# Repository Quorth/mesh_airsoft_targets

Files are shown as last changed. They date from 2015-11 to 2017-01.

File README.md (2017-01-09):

# mesh_airsoft_targets

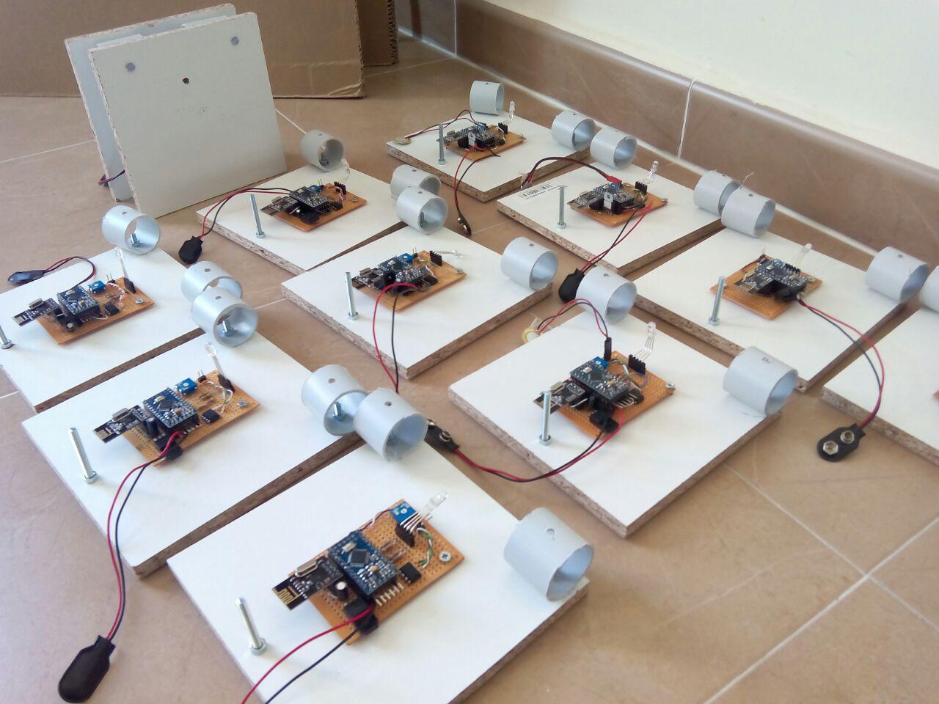
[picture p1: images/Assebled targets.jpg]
Assembled targets


Completed targets (piezo still not glued)

An arduino based airsoft targets with mesh networking capabilities. This is a WIP project originally made for the Murcia Lan Party event. But since it's been stalled for more than a year, we decided to release

We use the nrlf24l01 2.4Ghz modem and the RF24Mesh library to comunicate the targets with the master module

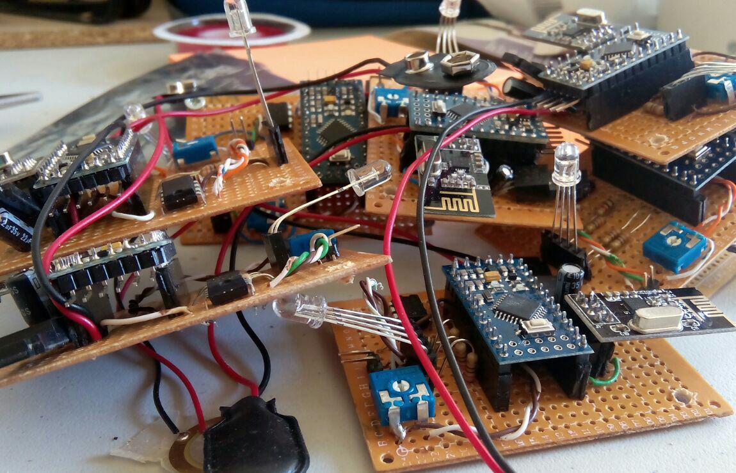
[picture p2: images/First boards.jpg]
First boards


First boards

The targets can control a RGB LED and reports the impacts to the master node, the games are implemented in the master module, so far we only have a sequential game with timing implemented

The impact detection is implemented via a piezoelectric transducer and a opamp for cleaning the pulse and setting sensitivity, you have the eagle schematics in target_node/board

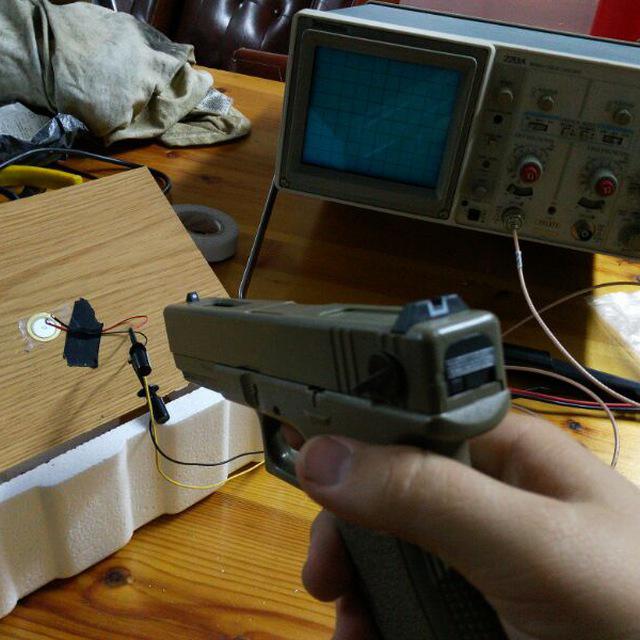
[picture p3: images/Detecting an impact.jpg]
Detecting an impact


Detecting an impact

The master module is an arduino board with a serial connection to the host the same board we use for the targets can be used as a master, but the idea is to eventually port to an OpenWRT target (like a TL703n) for networked operation or a BT link to a phone.

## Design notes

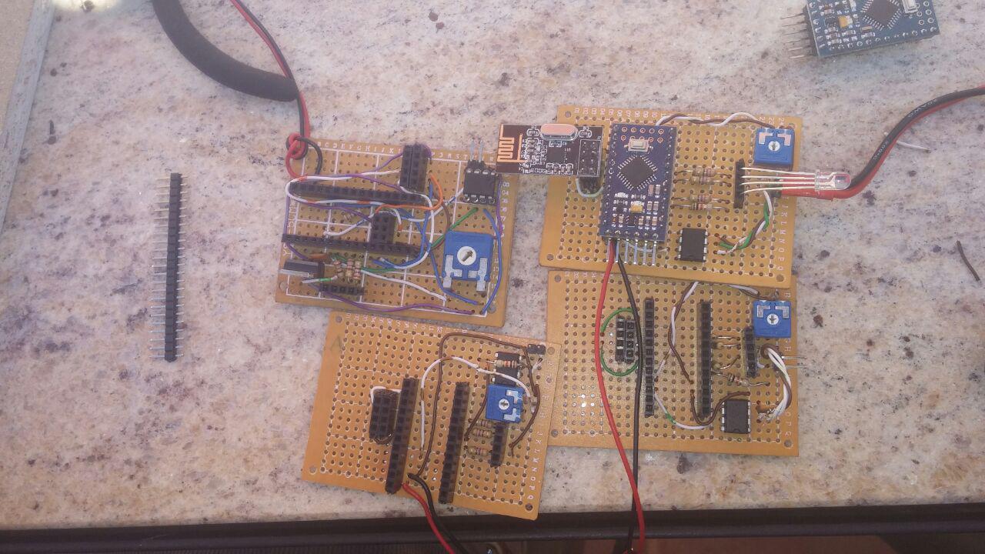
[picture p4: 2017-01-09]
images/First prototipes.jpg

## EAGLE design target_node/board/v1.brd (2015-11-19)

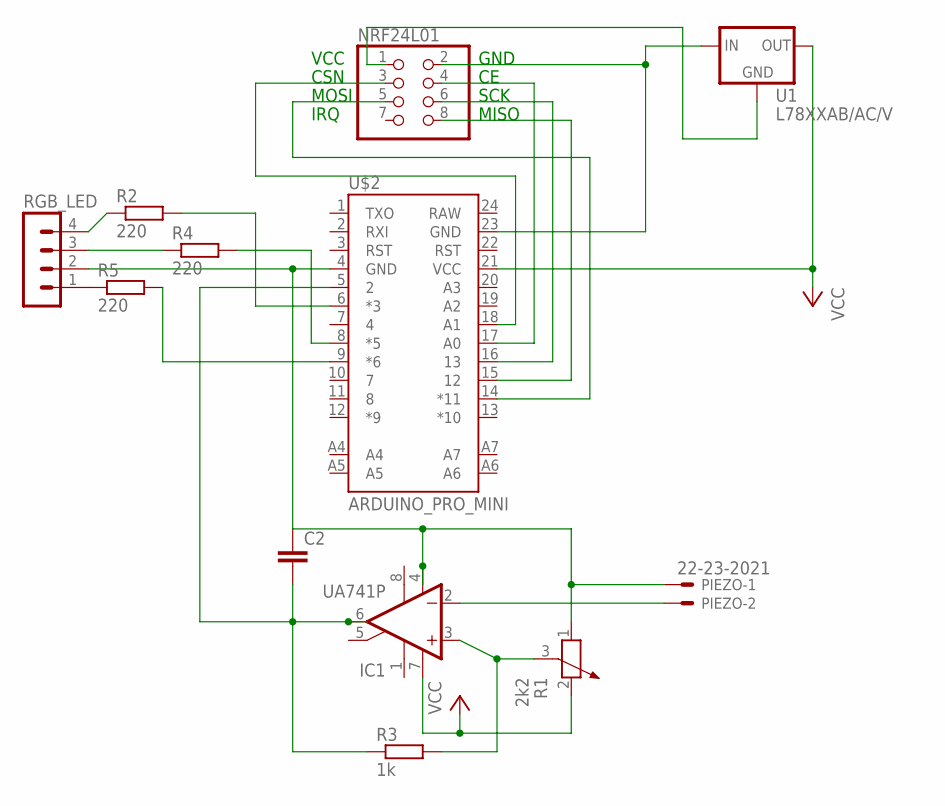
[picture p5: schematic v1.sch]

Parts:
C2: C-EU050-024X044; C050-024X044
IC1: UA741P; DIL08
NRF24L01: PINHD-2X4; 2X04
PIEZO: 22-23-2021
R1: 2k2; PT-10
R2, R4, R5: 220; 0207/10
R3: 1k; 0207/10
RGB_LED: MA04-1
U1: L78XXAB/AC/V; 78XXS
U$2: ARDUINO_PRO_MINI

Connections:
unnamed: NRF24L01.6, U$2.16 (13)
unnamed: NRF24L01.8, U$2.15 (12)
unnamed: NRF24L01.5, U$2.14 (*11)
unnamed: NRF24L01.4, U$2.17 (A0)
unnamed: R2.1, RGB_LED.4
unnamed: R4.1, RGB_LED.3
unnamed: R5.1, RGB_LED.1
unnamed: IC1.2 (-IN), PIEZO.2
unnamed: R2.2, U$2.6 (*3)
unnamed: R4.2, U$2.8 (*5)
unnamed: R5.2, U$2.9 (*6)
unnamed: C2.2, IC1.6 (OUT), R3.1, U$2.5 (2)
unnamed: NRF24L01.1, U1.GND
unnamed: NRF24L01.3, U$2.18 (A1)
unnamed: IC1.3 (+IN), R1.3, R3.2
unnamed: NRF24L01.2, U1.IN, U$2.23 (GND)
unnamed: C2.1, IC1.4 (V-), PIEZO.1, R1.1, RGB_LED.2, U$2.4 (GND)
VCC: IC1.7 (V+), R1.2, U1.OUT, U$2.21 (VCC)

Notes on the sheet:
VCC
GND
CSN
MOSI
SCK
IRQ
MISO

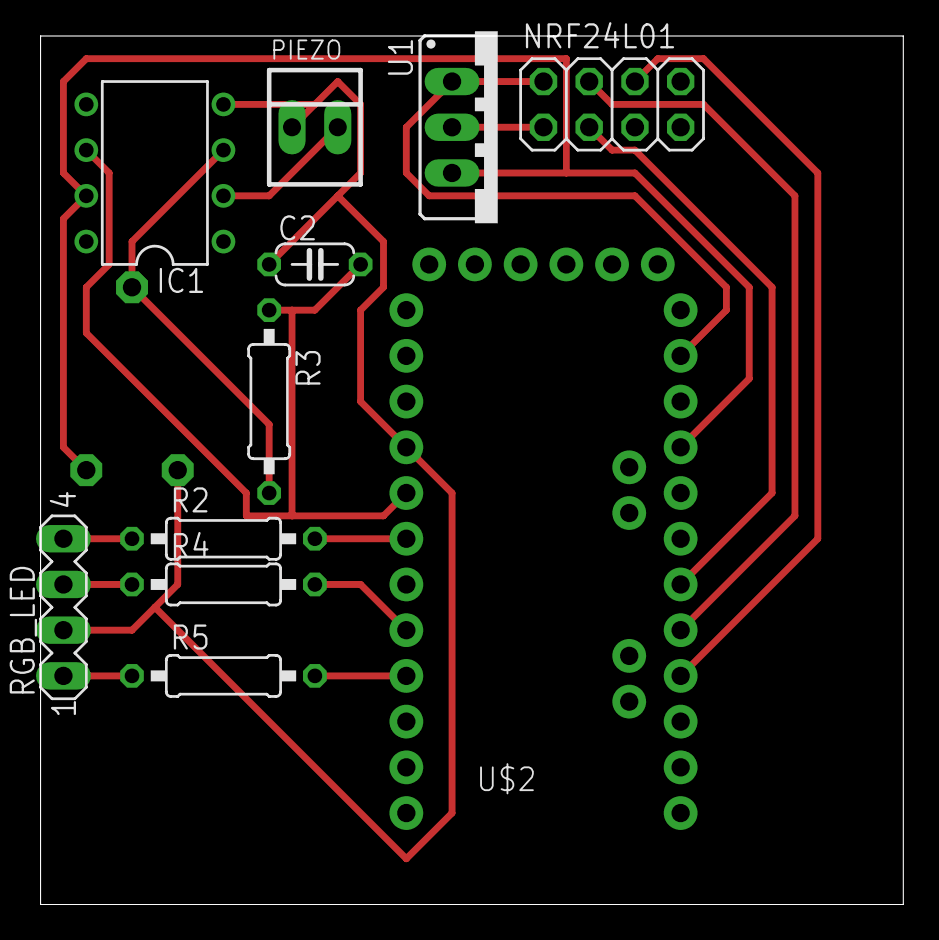
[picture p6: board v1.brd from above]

Board: 2 copper layers, 47.9 x 48.2 mm, 12 parts (1 on the bottom side), 18 nets.

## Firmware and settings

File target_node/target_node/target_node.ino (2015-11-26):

/** Airsoft Target - Target Node 
 *
 * The nodes will refresh their network address as soon as a single write fails. This allows the
 * nodes to change position in relation to each other and the master node.
 */
#include "RF24.h"
#include "RF24Network.h"
#include "RF24Mesh.h"
#include <avr/wdt.h>
#define TARGET_NODE
#include "lib_target.h"

#include <SPI.h>
#include <EEPROM.h>
//#include <printf.h>
/**** Configure the nrf24l01 CE and CS pins ****/
RF24 radio(14,15);
RF24Network network(radio);
RF24Mesh mesh(radio, network);
/**
 * User Configuration: nodeID - A unique identifier for each radio. Allows addressing
 * to change dynamically with physical changes to the mesh.
 *
 * In this example, configuration takes place below, prior to uploading the sketch to the device
 * A unique value from 1-255 must be configured for each node.
 * This will be stored in EEPROM on AVR devices, so remains persistent between further uploads, loss of power, etc.
 *
 **/

void setup() {
  
  Serial.begin(115200);
  
  attachInterrupt(0,toggle,FALLING);
  // Set the nodeID manually
  mesh.setNodeID(NODE_ID);
  // Connect to the mesh
  Serial.println(F("Connecting to the mesh..."));
  mesh.begin();
  Serial.println(F("Connected to the mesh!"));
  //lc[0] = {1,0,255,255,255};
  wdt_enable(WDTO_250MS);
  
}
void loop() {
  wdt_reset();
  mesh.update();
  
  // If interruption triggered, flag is set
  // so notify the master
  if (int_flag) {
    int_proc = 1;
    // Send an 'H' type message to notify a hit
    Serial.print("Hit received! Notifying to master... ");
    while (!mesh.write(&node_id,'H',sizeof(uint8_t))) {
      Serial.println("[FAILED]");
      // If a write fails, check connectivity to the mesh network
      if (!mesh.checkConnection()) {
        //refresh the network address
        Serial.print("Renewing Address... ");
        mesh.renewAddress();
        Serial.println("[OK]");
      } else {
        Serial.println("[FAIL]");
        Serial.println("Resending... ");
      }
    }
    Serial.println("[OK]"); 
    int_flag = 0;
    delay(100);
    int_proc = 0;
  }
  
  while (network.available()) {
    RF24NetworkHeader header;
    int led_id = 0;
    network.peek(header);
    switch(header.type){
      case 'C':
        Serial.println("Received new LED Command from master:");
        led_command lc_tmp;
        network.read(header,&lc_tmp,sizeof(lc_tmp));
        //Set the led command
        set_led_command(&lc_tmp);
        break;
      case 'R':
        network.read(header,0,0);
        Serial.print("Received address reset request. Renewing... ");
        mesh.renewAddress();
        Serial.println("[OK]");
        break;
      case 'G':
	network.read(header,&led_id,sizeof(led_id));
	Serial.print("Asked for LED command with LED id ");
	Serial.println(led_id);
	Serial.print("Sending data... ");
	while(!post_led_command(led_id)){
	   Serial.println("[FAIL]");
	   Serial.print("Resending... ");
	}
	Serial.println("[OK]");
	break;
      case 'O':	
	Serial.print("Received general OFF status from master. Turning off all leds...");
	network.read(header,0,0);
	turn_off_all();
	Serial.println("[OK]");
	break;
      case 'V':
	Serial.print("Master asking for node version...");
	network.read(header,0,0);
	post_version();
	Serial.println("[OK]");
	break;
      default:
	Serial.println("Received unknown command. Corrupted frame?");
	network.read(header,0,0);
        break;
    }
  }
  if(millis() - display_timer > 40){ //Update LED patterns @25fps
    update_leds();
    display_timer = millis();
  }
}
void toggle(){
    int_flag = int_proc==1 ? 0 : 1;   
}

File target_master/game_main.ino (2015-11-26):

void game_main(){
  switch(game){
    case 1:
      sequencial_game();
      break;
    case 0:
    default:
      if(network.available()){
        RF24NetworkHeader header;
        network.peek(header);
        Serial.println(header.toString());
        check_address(header);
        network.read(header,0,0);
      }// end if
      return;
  } 
}

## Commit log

2015-11-11 Initial commit. Added basic flow based on RF24Mesh examples. Added also custom library and function files
2015-11-11 Moved declarations to lib_target.h Deleted led_pinout struct and replaced with a const int array
    [target_node.ino]
2015-11-11 Added led command rx case on node targets
2015-11-11 Fixed detection of multiple interrupts with a single shoot
    [target_node.ino]
2015-11-17 Added previous files & staging schematics
    [v1.sch]
2015-11-17 Added first revision of the circuit and staging board
    [v1.brd]
2015-11-19 Changed schematic to connect nRF24 board to other digital outputs and make a single layer board
    [v1.brd, v1.sch]
2015-11-24 NODE BOARD: Changed schematic to easily fit on a single layered PCB -> CE and CS from nRF24 to pins 14 & 15 NODE FIRM: Changed CE and CS pins, changed interrupts from RISING to FALLING, changed folde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
2015-11-24 NODE FIRM: Fixed renew address command, fixed led command copy (now it works! :D)
    [functions_target.ino, target_node.ino]
2015-11-24 MASTER FIRM: fixed node address renewing control
    [target_master.ino]
2015-11-26 NODE FIRM: several fixes on command RX
    [target_node.ino]
2015-11-26 MASTER FIRM: Tested and fixed sequential game (now it works! :D)
    [functions_target.ino, game_main.ino, game_sequencial.ino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]

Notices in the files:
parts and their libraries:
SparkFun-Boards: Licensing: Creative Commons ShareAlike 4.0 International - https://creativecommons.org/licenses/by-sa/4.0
